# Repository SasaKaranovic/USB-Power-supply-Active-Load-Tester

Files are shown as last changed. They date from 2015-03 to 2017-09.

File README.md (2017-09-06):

# USB Power supply Active Load Tester

The USB Power Supply Active Load Tester is a unit designed for testing
the quality of power supplies.  The idea was to create a low-cost,
precise device for simultaneous measurement of voltage and current
draw from a device under test. This is one of my weekend projects that
I have decided to release to the public. If you are interested in my
other projects you can see them on [my homepage].

### Device Features:
- Open Source and Open Hardware
- Modular design, easy to understand and change/adapt to your needs
- Uses widely available and off-the shelf components
- Bill of Material is below $10
- Integrated USB-to-Serial converter for easier interface with the device
- API for communicating with PC
- Recording Voltage vs Amps data and graphing the results
- Easy to use

### Example plot of Voltage vs Current for 5V 1A adapter
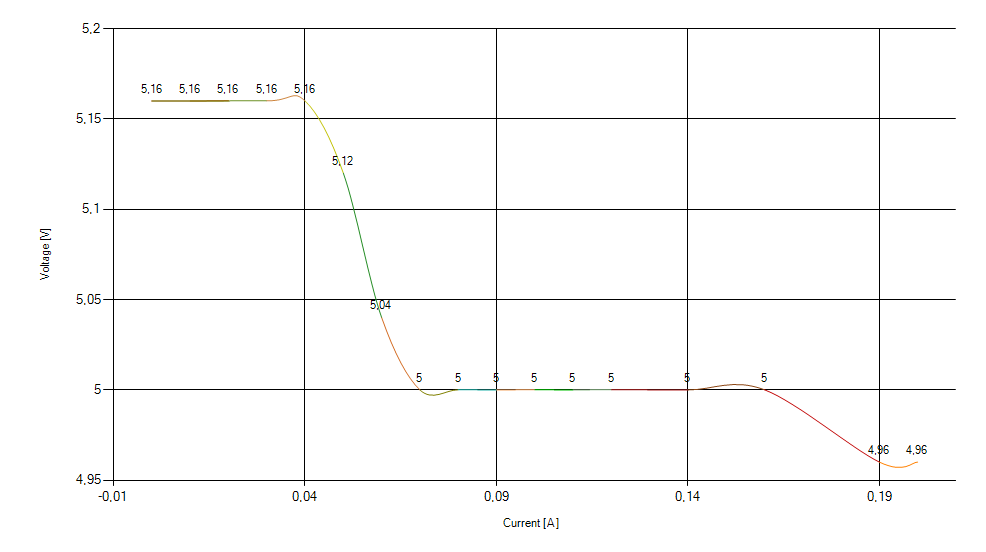
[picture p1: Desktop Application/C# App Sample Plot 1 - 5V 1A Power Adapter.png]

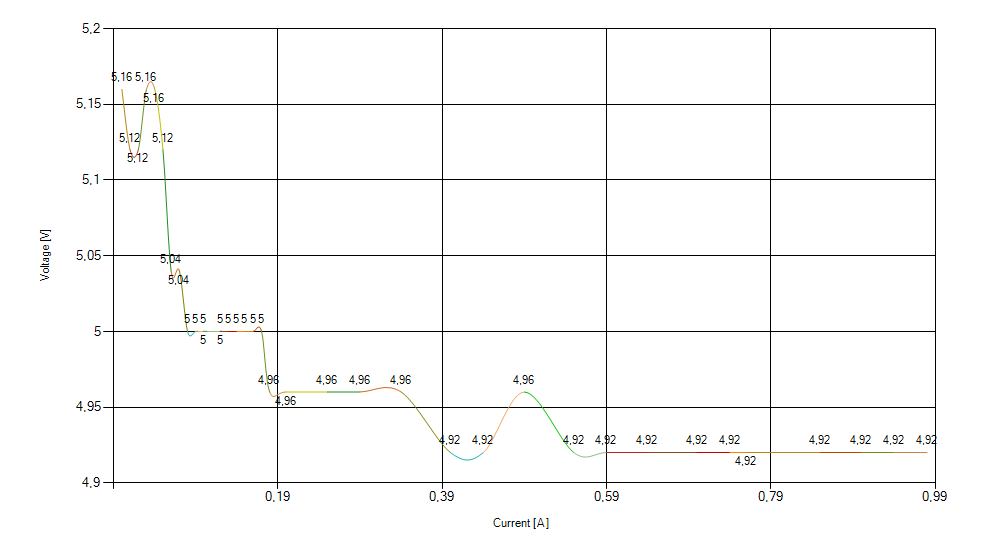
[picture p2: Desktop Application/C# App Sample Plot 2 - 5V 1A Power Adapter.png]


### Basic capabilities:
- PSU under test max voltage 55V
- Current Load of 5A (or more by lowering current sense resistor value)
- Current and Voltage measurement accuracy is below 5%

### Component list and estimated price:
- 1x - PIC16F1829 [$1.6]
- 1x - MCP6002 Rail-to-Rail OpAmp [$0.69]
- 1x - MCP4726 12bit DAC [$0.96]
- 1x - IRF L3705 Logic Level N-MOSFET [$0.5]
- 1x - CH340T USB-to-Serial converter [$0.99]
- 10x - Current sense 1 ohm 1% 1/2W resistor
- miscellaneous (resistors and capacitors)

Total components cost should be way under $10.

### How to build your own PAL Tester:
 If you are going to use photo etching or toner transfer method to make DIY board, there are bottom layer printouts in the Hardware folder that are ready for you to print and create a board via your favourite PCB manufacturing technique.

Once you have finished with developing, cleaning and drilling the board, in Hardware folder you have a file "Component-placement.png" which shows how and where to position components.

If you want to make changes or review the design, Schematic files (in .pdf) and Altium project files are available for download in Hardware folder. Open the design files in Altium or convert them to your favourite CAD and edit them.

### Device operation for laymans:
The microcontroller sets the voltage on the positive input of the Op
amp through a Digital-to-Analog converter (DAC).

The output of the op-amp then drives the N-MOSFET that allows current to flow.  

The negative input of op-amp is connected to the sensing resistor (Rs) that is between the source of the N-MOSFET and GND.

The voltage across Rs (and thus voltage on the negative input of the op-amp) is proportional to the current flowing through the resistor. For 1 Ohm resistor, V=1 ohm x Current draw.

Since an op-amp "tries to equalize positive and negative inputs", suppose the voltage on its positive input is 1V. To equalize positive and negative inputs, the voltage on the negative input (the one that is connected to Rs) must also be 1V, so the op-amp drives the N-MOSFET to open, allowing the current to flow, but only enough to make 1V on the negative input. Calculating the current draw from the above mentioned formula, we see that in this example, the current draw will be 1A.

### Development

Want to contribute? Great!

Currently there is a C# .NET application written for interfacing with the device. It works but it's very rough and very basic. If you are interested in writing an application in Python, C++, C or any other language, please do. I would greatly appreciate that. Also if you need help or more information, feel free to contact me over Skype, Email, IRC or whatever way you like. :)

Also if you think you can help in any other way, please do. Any kind of help is greatly appreciated.

Special thanks to
----
- Loshki from #electronics @ Freenode
- Your name here :)

Contact me
----
[Sasa Karanovic Home] - Follow me [@Twitter] - [Facebook] - [YouTube] - [EMail]

License and Disclaimer
----
You are using this software and hardware at your own risk.

**Open Source, Open Hardware. Do WHATEVER your want :)**

[Sasa Karanovic Home]:http://sasakaranovic.com
[my homepage]:http://sasakaranovic.com
[YouTube]:http://sasakaranovic.com/youtube
[@Twitter]:http://twitter.com/iSaleK
[Facebook]:https://www.facebook.com/SasaKaranovic
[EMail]:mailto:sale@mrdnise.com

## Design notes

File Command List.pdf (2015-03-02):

## PAL Unit (Power supply Active Load)

# Command list

Command | Value range | Description | Example
S:xxxx | 0 – VCC* | Set DAC output voltage to xxxx mV. For 1Ω sens resistor current draw will be equal to DAC output voltage. | S:0500 → Sets target current draw to 0.5A [for 1Ω sens resistor]
C:M00x | 0 or 1 | Continous reading off/on. In continuous mode device sends Current and Voltage readings every delay* period of time. | C:M001 → ON C:M000 → OFF
C:Dxxx | 1 to 255 | Continuous mode delay period. Device will wait for xxx * 100ms before sending new values. | C:D005 → Device will send readings every 5 * 100ms = 500ms
C:Onnn | / | Issue on demand read. Device will read Power Supply under test voltage, current draw and DAC output voltage and send them over UART. | C:0xxx → Read current values and send over UART once.

# Example output

Command | What happens | Example output on UART
S:0500 | DAC output voltage will be set to 500mV or 0.5V If 1Ω sens resistor is used, device will try to draw 500mA or 0.5A from the Power Supply Under Test. | PSV:12.00V\r\n PSI:0.50A\r\n
C:M001 | Continuous mode is turned on. Device will send readings every *delay* seconds. | PSV:12.00V\r\n PSI:0.50A\r\n
C:Onnn | Issue a on-demand read request. Device will read values and send them over UART but only once. | PSV:12.00V\r\n PSI:0.50A\r\n OPA:0.50V\r\n

http://sasakaranovic.com/project/USB-PAL-Tester/https://github.com/coldkeyboard/USB-PAL-Tester

Version 0.6
2015-02-23

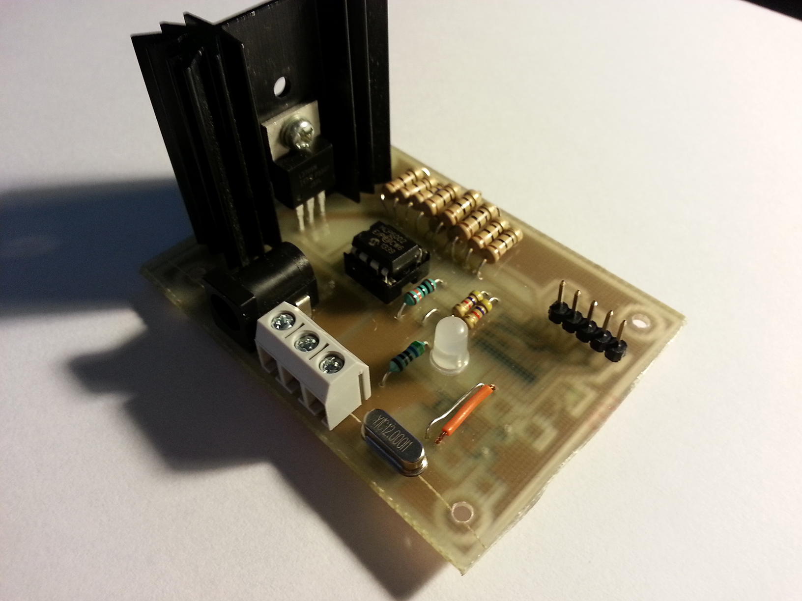
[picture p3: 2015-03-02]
Hardware/PAL Unit Top.jpg

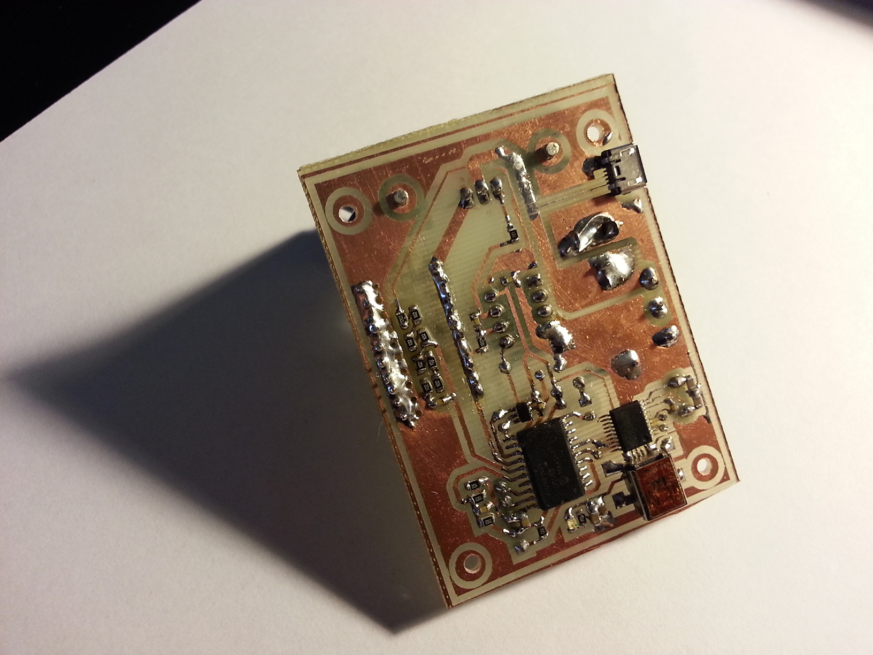
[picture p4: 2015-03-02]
Hardware/PAL Unit Bottom.jpg

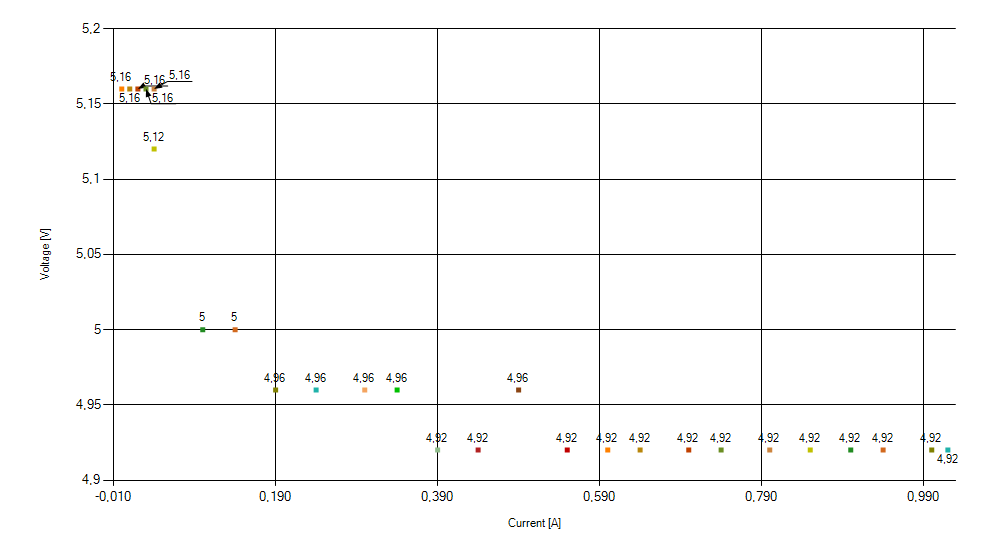
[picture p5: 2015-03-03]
Desktop Application/C# App Sample Point Plot 3 - 5V 1A Power Adapter.png

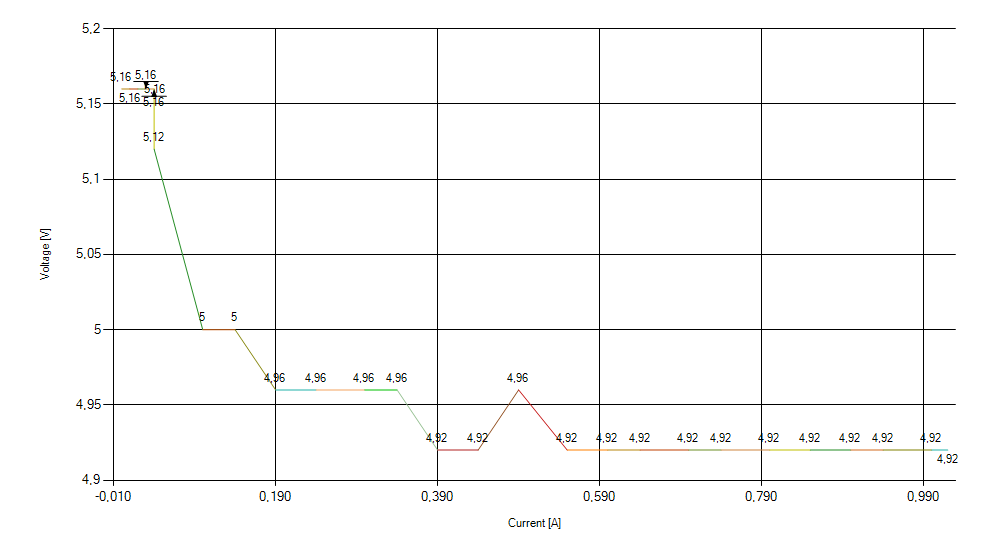
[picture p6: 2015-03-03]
Desktop Application/C# App Sample Line Plot 3 - 5V 1A Power Adapter.png

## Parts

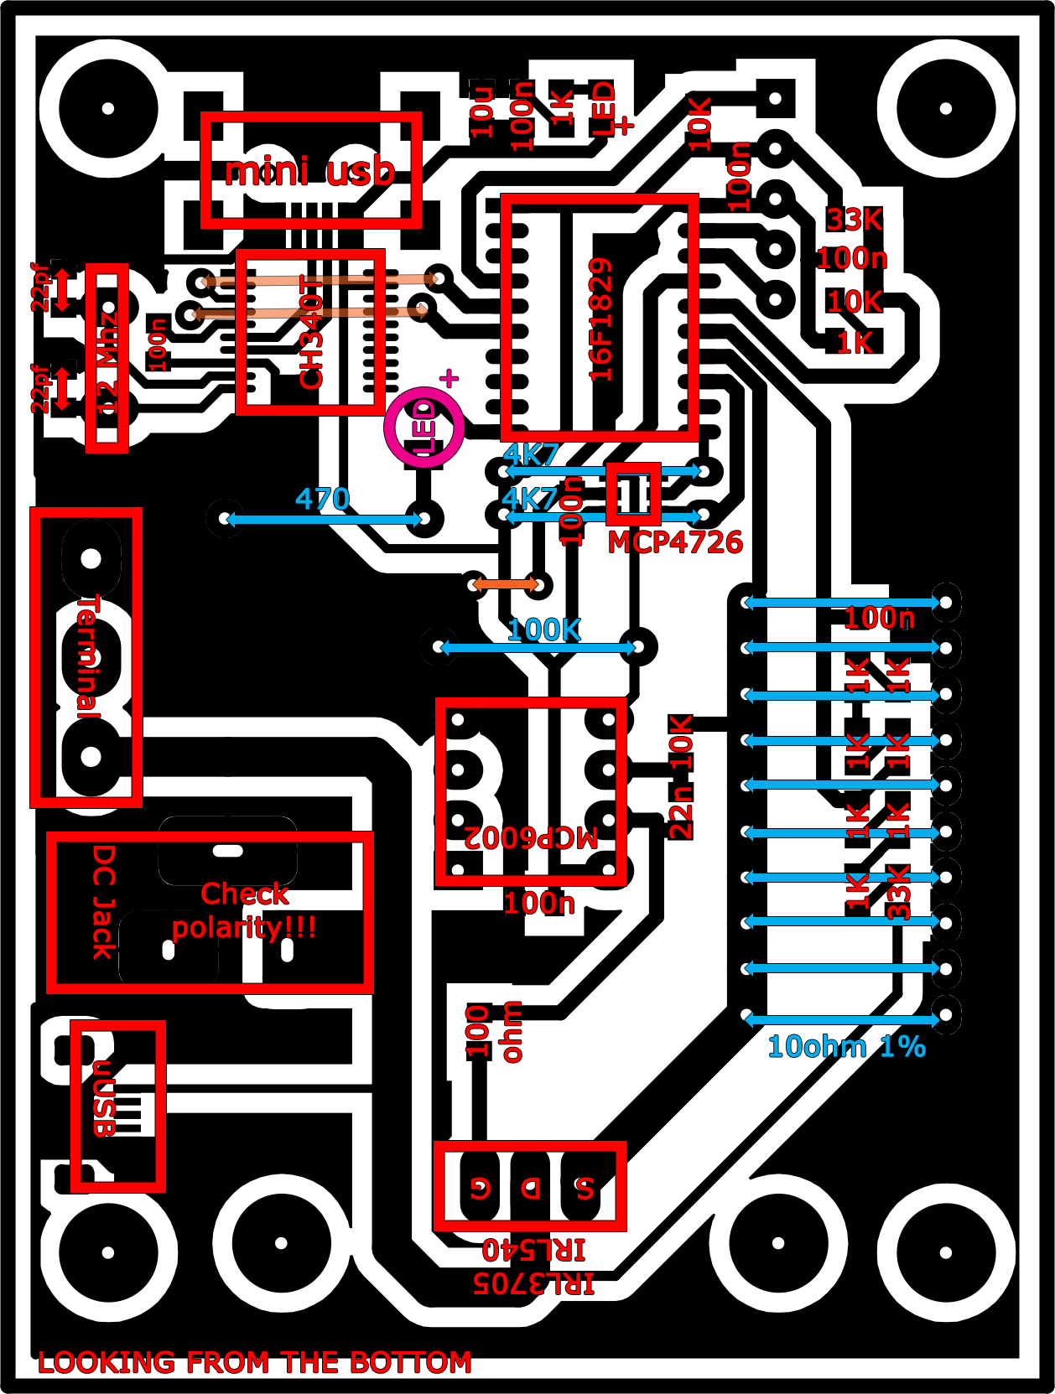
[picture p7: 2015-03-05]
Hardware/Component-placement.png

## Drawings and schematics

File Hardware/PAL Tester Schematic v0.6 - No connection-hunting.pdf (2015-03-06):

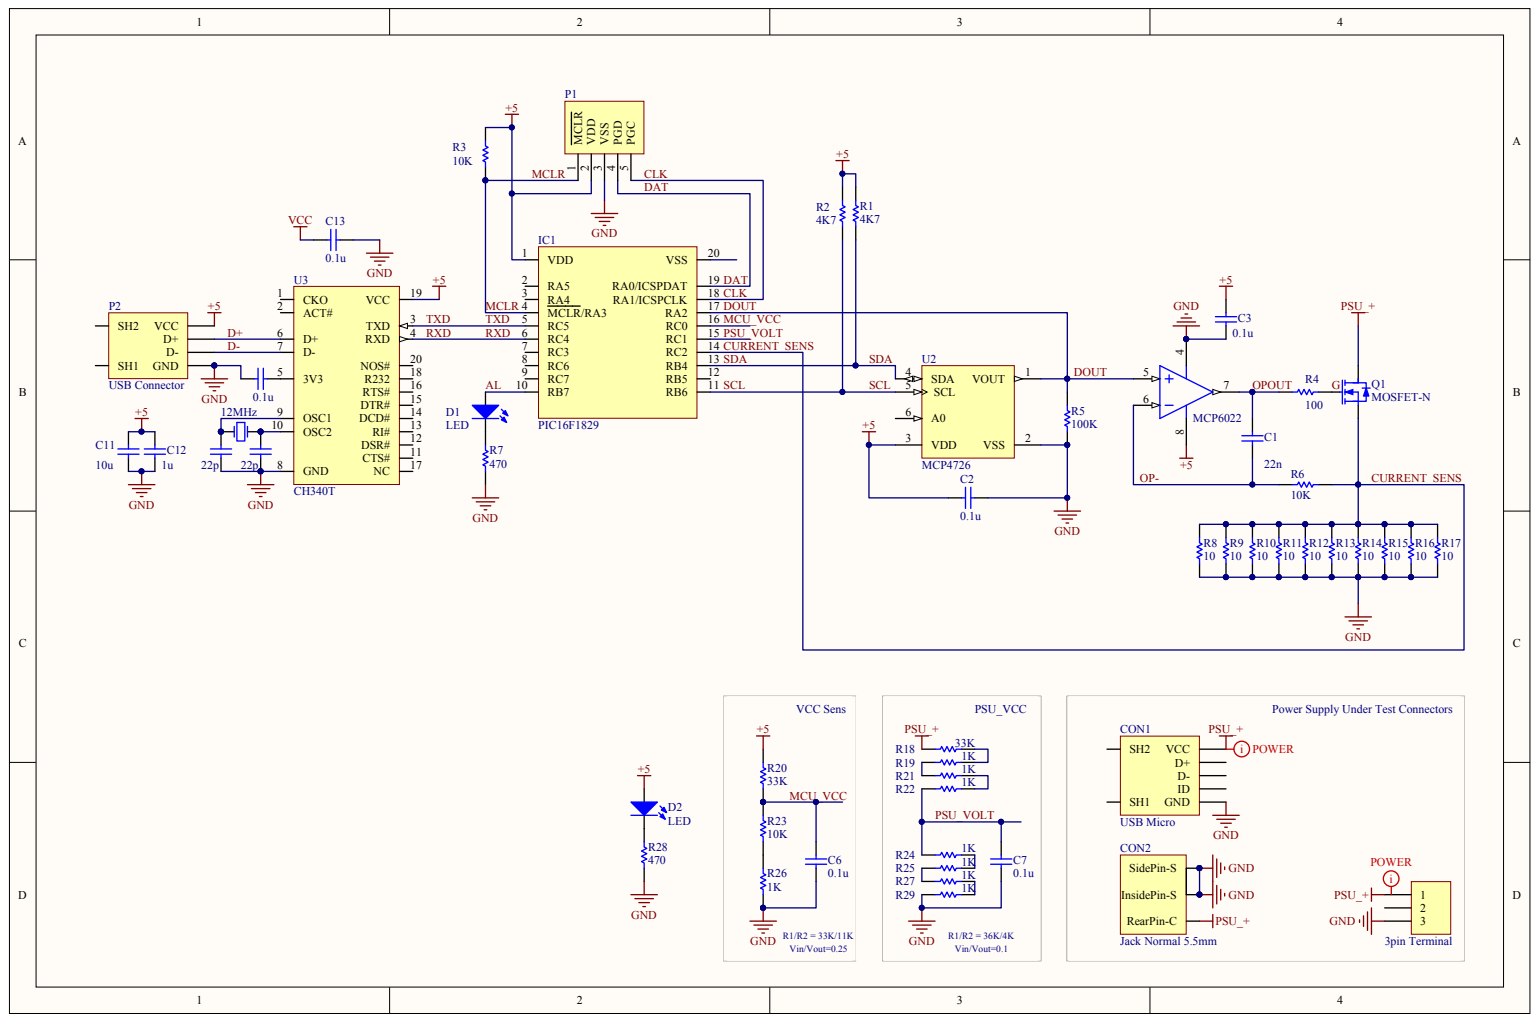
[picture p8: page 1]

Power Supply Under Test Connectors

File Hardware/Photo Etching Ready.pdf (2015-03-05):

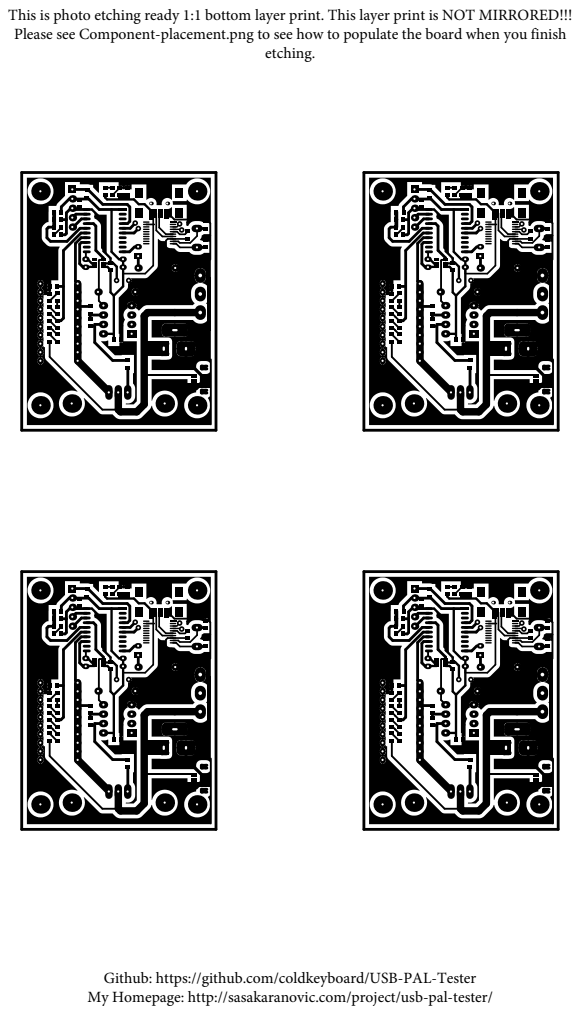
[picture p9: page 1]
etching.

This is photo etching ready 1:1 bottom layer print. This layer print is NOT MIRRORED!!!
Please see Component-placement.png to see how to populate the board when you finish

Github: https://github.com/coldkeyboard/USB-PAL-Tester
My Homepage: http://sasakaranovic.com/project/usb-pal-tester/

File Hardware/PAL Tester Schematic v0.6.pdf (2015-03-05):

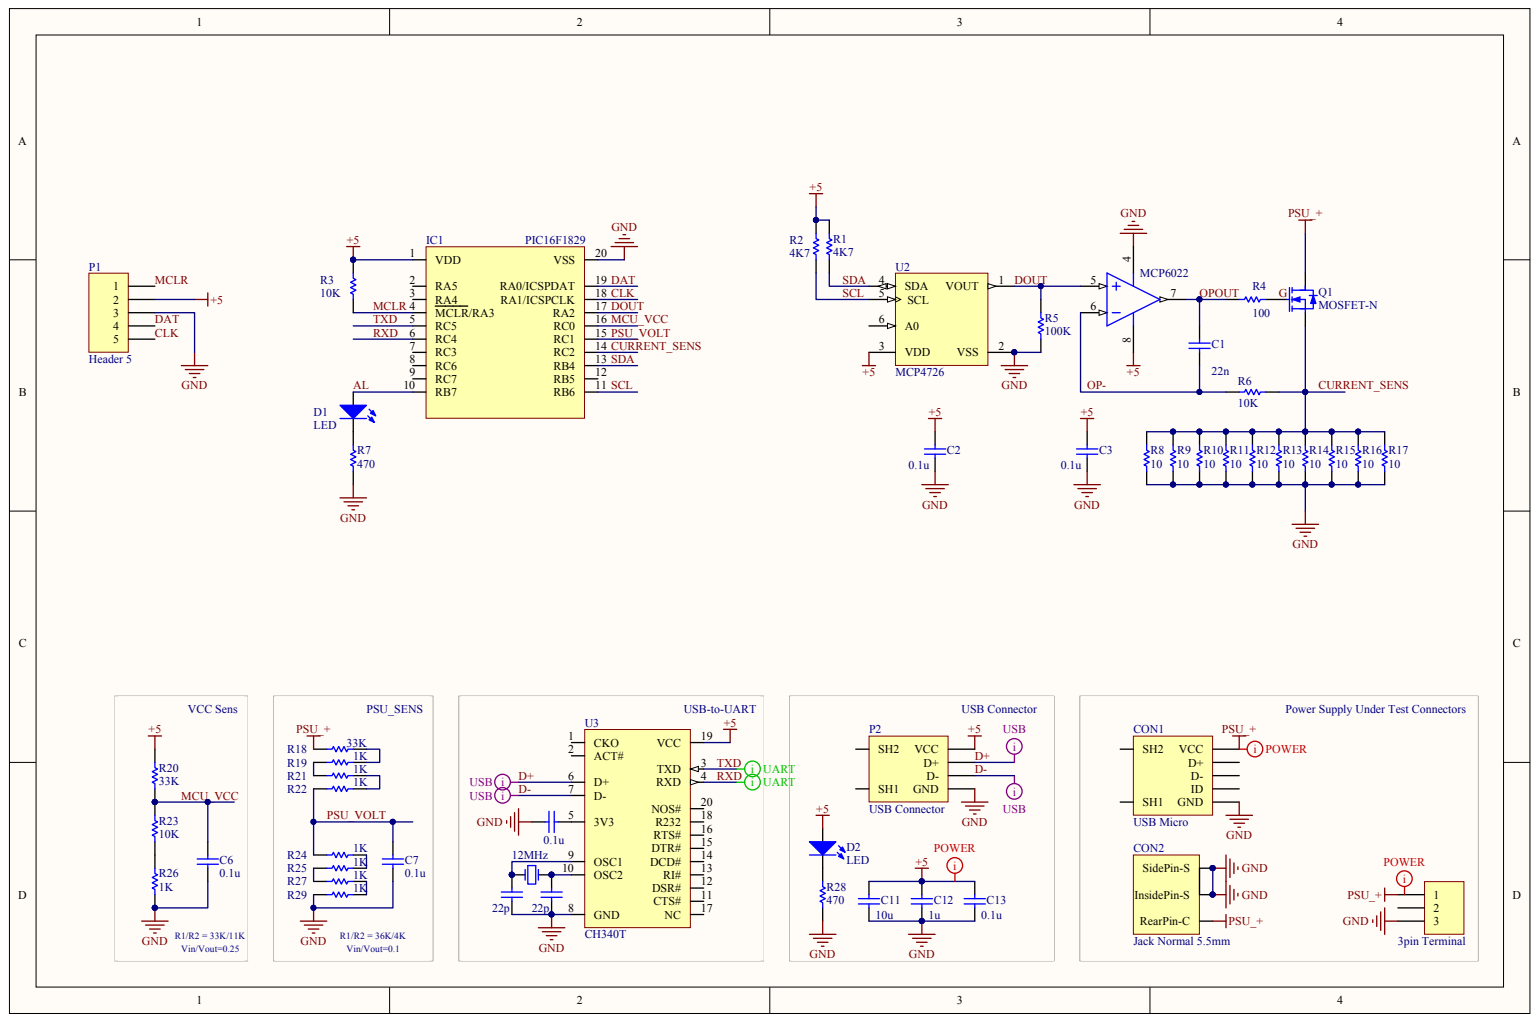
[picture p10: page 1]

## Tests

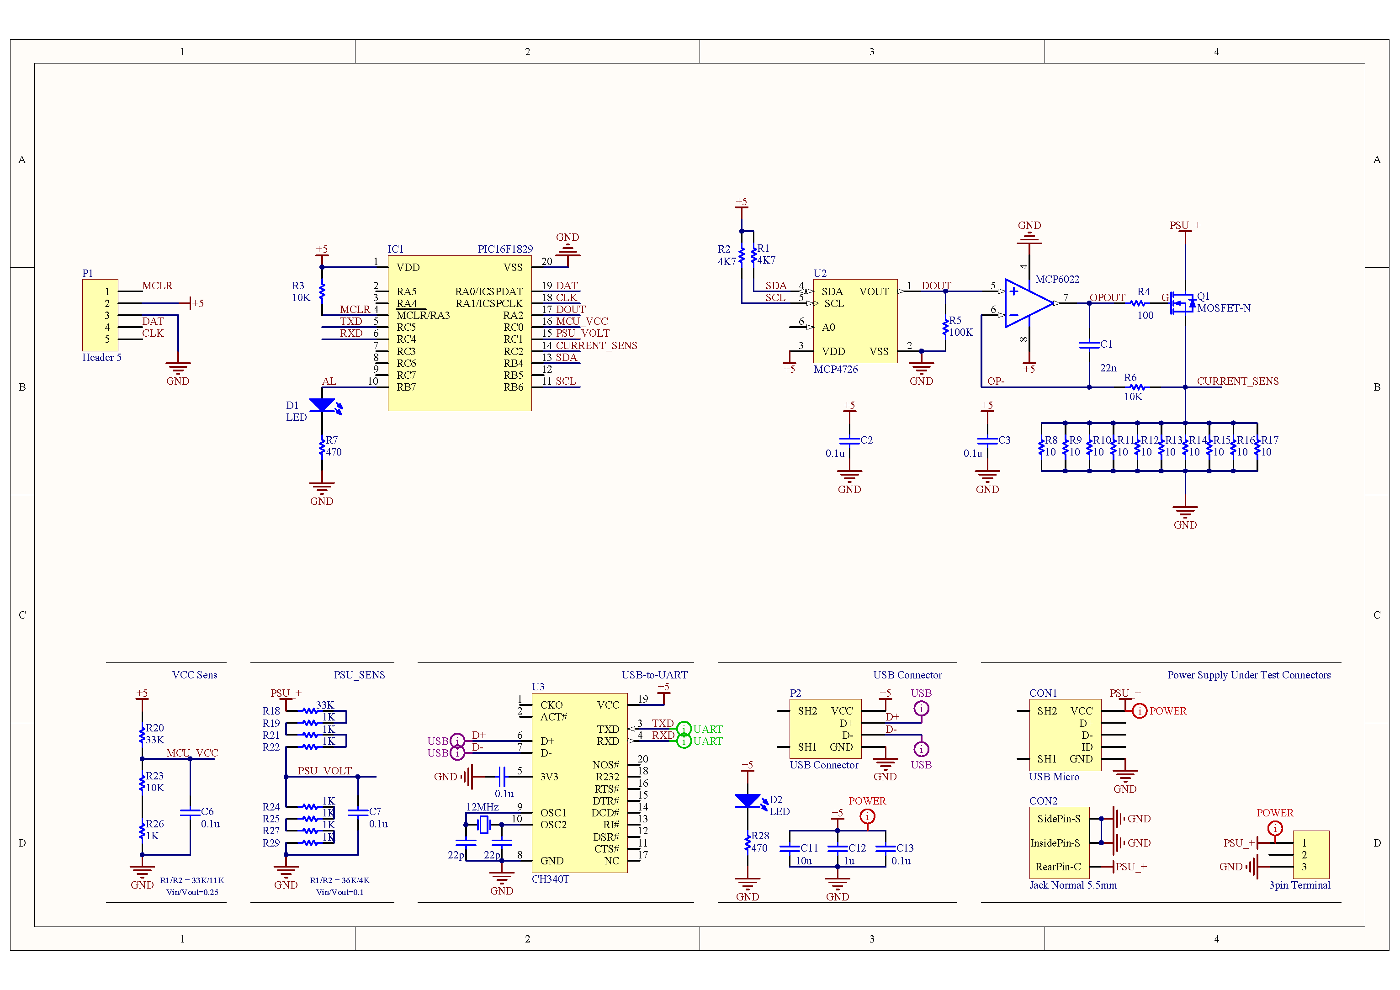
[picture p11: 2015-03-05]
Hardware/PAL Tester Schematic v0.6.png

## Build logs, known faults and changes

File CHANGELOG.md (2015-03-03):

# Change Log
All notable changes to this project will be documented in this file.
This project adheres to [Semantic Versioning](http://semver.org/).

## [0.6.1] - 2015-03-03
### Added
- Added examples of Line, SpLine and Point charts to /Desktop Application/ folder.

### Changed
- Desktop Application now has options to clear graph, change graph type and save graph (was available from the beginning but was hidden under chart double-click and by default saved at c:\).
- Desktop Application should now display proper values for X-axis

## [0.6] - 2015-03-01
### Added
- C# Source files and compiled application written in C# to interface with the device
- Command List.pdf - Contains commands list, explanations and example input and UART output.
- Command [C:M00x] to chose between continuous sending of Voltage and Current draw readings
 and on demand. x means 1=Continuous, 0=On Demand
- Command [C:Dxxx] to set delay in continuous mode. xxx is delay of xxx*100ms. [eg. 005 -> 500ms delay]
- Reading of device VCC rail via resistor divider and using that data to further
self-calibrate the device.
- Using VCC_voltage/4096 as DAC quant instead of 5V/4096 making the device more precise
and immune to the VCC rail noise/fluctuation.
- Added function to issue self recalibrate command.
- ACTIVITY LED to notify user when changes have been received/applied and as a general
indication of activity.
- MCU POWER LED for indication if device is powered up
- PSU under test VOLTAGE PRESENT LED indicating that MCU is measuring voltage above 1V
between + and - leads of the PSU under test.

### Changed
- \r\n moved from the start of the string to the end of the string.
- UART Receiver Interrupt handling routine (aka RX ISR) has become too big so I've moved it
to separate file called ISRFunctions.h and ISRFunctions.c This should improve code readability
and also simplify the process of adding support for new commands.
ISR is still big but at this moment it "has to be". At least it should be easy to follow.
- UART Set/Read API made more coherent. Using S:xxxx for SET voltage and C:xxxx for configuring
and communicating with the device.
- Command and function names have been renamed to further reflect what peripheral/device
they belong to and set to easier to read format. (still a lot of work to do here...)

## [0.5] - 2015-02-01
### Added
- General "human readable" API to set/read data from the device. Hopefully making
use of this device with other software easier and more pleasant. :)

### Fixed
- Issues where after disconnecting UART or re-powering the device, last programmed
target current draw will remain and be immediately set as new target causing unwanted
stress or overload on the PSU under test
- Overflowing the DAC/VCC value will result in no status change instead of resetting to 0A draw.
Also an error message will be sent over UART notifying the user.

## [0.4] - 2015-01-21
### Added
- Code to support DAC I2C communication.
- Code to support UART setting target current draw from the PSU under test.

### Changed
- Modified schematic to house potentiometer with MCP4726 (12bit DAC) to enable users to set
target current draw via UART or set manual mode.

## [0.3] - 2015-01-18
### Changed
- Switched to using 5V rail for MCU.
- Switched to using MCP4002 (rail-to-rail) OP-Amp instead of LM324.
- Miscellaneous (minor) changes to voltage dividers and sensing resistor.

## [0.2] - 2015-01-17
### Changed
- Changed function descriptions and names to be more coherent.

### Added
- Reading voltage from potentiometer (besides PSU VCC and voltage on sensing resistor).
- Functions to send VCC, Resistor Voltage and PSU Voltage over UART in more convenient form.

## [0.1] - 2015-01-15
### Added
- Initial build.

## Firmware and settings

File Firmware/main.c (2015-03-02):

/*
 *  Project     : Programmable Active Dummy Load
 *  Code Version: 0.6 (see change log for more information and what's changed)
 *  Compile with: Microchip XC8 v1.31 or up (free compiler)
 *  Hardware    : - PIC16F1829
 *                - MCP4726   (12bit DAC)
 *                - MCP6002   (2x Rail-to-Rail OP-Amp)
 *                - Logic Level N-MOSFET (IRLxx in TO-220 case)
 *                - USB-to-UART converter (FTDI, CH340 or any other)
 *
 *  Description : As the title implies, this is the source code of the programmable active load
 *  unit. Latest source code, design files, schematic, Bill of Material, HOW-TO and lot's of other
 *  useful information about this project can be found on:
 *  My Homepage: http://sasakaranovic.com/projects/usb-pal-tester/
 *  GitHub     : https://github.com/coldkeyboard/USB-PAL-Tester
 *
 * 
 *  Nice feature is that this unit is completely programmable via USB, so you can write little
 *  Python, C, C++, .NET app that will do series of tests on your Power Supply that you want to
 *  check and log that data or plot it on the graphs to see the Power Supply characteristics.
 *
 *  Device configuration and readings are done over the serial communication or UART.
 *  With commands like S:3000 the MCU will set-up DAC to set 3000mV or 3.000V on its output.
 *  DAC Output is connected to + Op Amp which is driving the N-MOSFET that acts like dummy load.
 *  Drain of mosfet is connected to Power Supply + that we want to test/stress. Source of the
 *  MOSFET is connected to the ground via small sensing resistor, 1ohm/1% or better. So having
 *  that in mind, and how OP-amps and MOSFETS work, our dummy load will try to draw 3Amps from
 *  the power supply under test. This little unit will send values like how much Amps are we
 *  drawing from the Power Supply under test, what voltage is across Power Supply under test,
 *  what is the output of the DAC (set current) and etc.
 *
 *  All of the files provided (including but not limited to schematics, source-code, drawings and etc.)
 *  are provided "as-is" without any guarantee and you are using them on your own risk.
 *
 *  All of the files provided are completely open-source. You can do whatever you want with them.
 *
 * I would really appreciate if you would share your designs, modifications, opinions, suggestions
 *  and etc. with me/others so we can all share and collaborate on this project.
 *
 * Also if you like this project or want to show your support, please consider donating (your time,
 *  opinion, review, code modifications, suggestions, request, beer, coffee or anything else you want). :)
 *
 */

#include "main.h"

//Value to send to DAC (VCC/DAC_RESOLUTION * SET_VOLTAGE)
uint16_t DAC_Target_Voltage = 0;

uint16_t ADC_val_VCC            = 0;
uint16_t ADC_val_PSUVCC         = 0;
uint16_t ADC_val_Current        = 0;

//UART ISR values
uint8_t ISR_RX_TEMP;        //Read to this temp variable
uint8_t ISR_RX_BUFF[10];    //Buffer to store RX characters
uint8_t ISR_RX_COUNT = 0;   //Counter for UART RX characters
uint8_t ISR_RX_STATE = 0;   //State of the current UART recieve process
uint8_t ISR_RX_MODE  = 0;   //Are we receiving command to set DAC (S:) or other parameters (C:)

//Configuration
uint8_t CONF_CONTINUOS_SEND         = 0;    //1 -> Send VCC, Current and Voltage Values continuously
uint8_t CONF_CONTINUOS_DELAY        = 10;    //Delay in (this_value)*100ms
uint8_t CONF_CONTINUOS_DELAY_TMP    = 10;    //Temp value used for creating dynamic delay
uint8_t ONDEMAND_PENDING            = 0;

void main()
{
    Device_SetUp();
    Device_Initialize();

    //Measure VCC to make sure our FVR can work properly
    ADC_val_VCC = ADC_MeasureVCC();

    UART_SendVCC(ADC_val_VCC);
    UART_Send_PSU_VoltAmp();
    UART_Send_OPAMP_Voltage();


    while(1)
    {
        if(CONF_CONTINUOS_SEND == 1)      //Continous mode enabled
        {
            UART_Send_PSU_VoltAmp();     //Send PSU Voltage and Current(amps) draw

            CONF_CONTINUOS_DELAY_TMP = CONF_CONTINUOS_DELAY;
            while(--CONF_CONTINUOS_DELAY_TMP) { _delay_ms(100); }
        }
        else if(ONDEMAND_PENDING == 1)
        {
            UART_Send_PSU_VoltAmp();     //Send PSU Voltage and Current(amps) draw
            UART_Send_OPAMP_Voltage();
            ONDEMAND_PENDING = 0 ;
        }

    }
}


//Interrupt Handling
void interrupt ISRRoutine(void)
{
    //USART RX Interrupt
    if (PIE1bits.RCIE && PIR1bits.RCIF) {
        PIE1bits.RCIE  = 0;    //Disable receive interrupts
        PIR1bits.RCIF  = 0;

        ISR_RX_TEMP = RCREG;

        #ifdef _DEBUG_UART_
        //putch(RCREG);   //Loopback sent character
        #endif

        LEDACTIVITY     = 1;
        

        //Check if we are receiving SET command for DAC
        if(ISR_RX_STATE == 0)
        {
            if(ISR_RX_TEMP == 'S')          { ISR_RX_MODE = 1; ISR_RX_STATE    = 1; }
            else if (ISR_RX_TEMP == 'C')    { ISR_RX_MODE = 2; ISR_RX_STATE    = 1; }
            ISR_RX_COUNT    = 0;
        }
        //2nd character must be : to indicate we are receiving S: or C: command
        else if (ISR_RX_STATE == 1 && ISR_RX_TEMP == ':') { ISR_RX_STATE = 2; }
        //followed by 4 ASCII characters
        else if (ISR_RX_STATE == 2 && ISR_RX_COUNT < 4)
        {
     
            ISR_RX_BUFF[ISR_RX_COUNT] = ISR_RX_TEMP;
            ++ISR_RX_COUNT;
            if(ISR_RX_COUNT == 4) { ISR_RX_STATE = 3; }
        }

        if (ISR_RX_STATE == 3)
        {    //Receiving complete. All 4 characters are in ISR_RX_BUFF
            
            if(ISR_RX_MODE == 1) { ISR_SetDAC(ISR_RX_BUFF); }   //Set DAC command received
            else if ( ISR_RX_MODE == 2) { ISR_Command_Mode(ISR_RX_BUFF); }    //Control command is received

            ISR_RX_STATE    = 0;
            ISR_RX_MODE     = 0;
        }

        LEDACTIVITY = 0;

        PIE1bits.RCIE  = 1;    //Enable receive interrupts
        return;
    }
}

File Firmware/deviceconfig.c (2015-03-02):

#include "main.h"

void Device_SetUp()
{
#ifdef _PIC16F1829_H_
    //Configure oscillator for 32MHz (8MHz 4xPLL)
    OSCCONbits.SPLLEN   = 1;        //1 = 4xPLL Is enabled
    OSCCONbits.IRCF     = 0b1110;   //1110 = 8 MHz or 32 MHz HF(see Section 5.2.2.1 ?HFINTOSC?)
    OSCCONbits.SCS      = 0b00;     //00 = Clock determined by FOSC<2:0> in Configuration Word 1.

    //wait for oscillator to stabilise
    while(!OSCSTATbits.HFIOFR);         //1 = HFINTOSC is ready
    while(!OSCSTATbits.HFIOFS);         //1 = HFINTOSC is at least 0.5% accurate
    while(!OSCSTATbits.PLLR);           //1 = 4xPLL is ready



    //Configure Activity LED
    TRISACTIVITY  = OUTPUT;
    LEDACTIVITY   = 0;

#else
#warning "DeviceSetup() function is empty for this device"
#endif
}

void SetUpInterrupts()
{
#ifdef _PIC16F1829_H_
    INTCONbits.PEIE = 1;
    PIE1bits.RCIE   = 1;
    INTCONbits.GIE  = 1;


#else
#warning "SetUpInterrupts() function is empty for this device"
#endif

}


void UARTSetup(uint16_t baudrate)
{
#ifndef _XTAL_FREQ
    #warning _XTAL_FREQ is not defined!;
#endif
#ifdef _PIC16F1829_H_
    //Select and configure RX/TX pins
    APFCON0bits.RXDTSEL = 1;    //1 = RX/DT function is on RC5
    APFCON0bits.TXCKSEL = 1;    //1 = TX/CK function is on RC4

    
    TRISCbits.TRISC5    = INPUT;
    TRISCbits.TRISC4    = OUTPUT;
    LATCbits.LATC4      = 1;

    //Configure baudrate
    BAUDCONbits.BRG16   = 1;    //1 = 16-bit Baud Rate Generator is used
    uint16_t baud = (( (_XTAL_FREQ / baudrate) / 4 ) - 1);
    SPBRGL  = (baud & 0xFF);
    SPBRGH  = (baud >> 8);

    //Configure TX and RC registers
    TXSTAbits.BRGH  = 1;        //1 = High speed
    TXSTAbits.TXEN  = 1;        //1 = Transmit enabled
    RCSTAbits.CREN  = 1;        //1 = Enable Receive
    RCSTAbits.SPEN  = 1;        //1 = Serial port enabled (configures RX/DT and TX/CK pins as serial port pins)

    _delay_ms(10);  //Give UART some time to stabilise (not necessary)

#else
#warning "SetupUART() function is empty for this device"
#endif
    
}





void putch(uint8_t data) {
    while(TXSTAbits.TRMT != 1);
    TXREG = data;
}



void Device_Initialize()
{
    UARTSetup(57600);
    LEDACTIVITY = 1;
    _delay_ms(100);
    UART_Debug("UART IS ON\r\n");
    ADC_Config();
    UART_Debug("ADC IS ON\r\n");
    I2C1_Setup();
    UART_Debug("I2C is ON\r\n");

    //Initialize DAC to 0V
    mcp4726_SetValue(0);
    _delay_ms(500);
    LEDACTIVITY = 0;

    //SetUp Interrupts
    SetUpInterrupts();

}

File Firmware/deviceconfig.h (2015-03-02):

#ifndef DEVICECONFIG_H
#define	DEVICECONFIG_H

//Configuration bits for PIC16F1829
#ifdef _16F1829
// CONFIG1
#pragma config FOSC = INTOSC    // Oscillator Selection (INTOSC oscillator: I/O function on CLKIN pin)
#pragma config WDTE = OFF       // Watchdog Timer Enable (WDT disabled)
#pragma config PWRTE = OFF      // Power-up Timer Enable (PWRT disabled)
#pragma config MCLRE = ON       // MCLR Pin Function Select (MCLR/VPP pin function is MCLR)
#pragma config CP = OFF         // Flash Program Memory Code Protection (Program memory code protection is disabled)
#pragma config CPD = OFF        // Data Memory Code Protection (Data memory code protection is disabled)
#pragma config BOREN = ON       // Brown-out Reset Enable (Brown-out Reset enabled)
#pragma config CLKOUTEN = OFF   // Clock Out Enable (CLKOUT function is disabled. I/O or oscillator function on the CLKOUT pin)
#pragma config IESO = ON        // Internal/External Switchover (Internal/External Switchover mode is enabled)
#pragma config FCMEN = ON       // Fail-Safe Clock Monitor Enable (Fail-Safe Clock Monitor is enabled)

// CONFIG2
#pragma config WRT = OFF        // Flash Memory Self-Write Protection (Write protection off)
#pragma config PLLEN = OFF       // PLL Enable (4x PLL disable)
#pragma config STVREN = ON      // Stack Overflow/Underflow Reset Enable (Stack Overflow or Underflow will cause a Reset)
#pragma config BORV = LO        // Brown-out Reset Voltage Selection (Brown-out Reset Voltage (Vbor), low trip point selected.)
#pragma config LVP = ON         // Low-Voltage Programming Enable (Low-voltage programming enabled)



//Activity (LED Anode) PIN
#define TRISACTIVITY    TRISBbits.TRISB7
#define ANSELACTIVITY   ANSELBbits.ANSB7
#define LEDACTIVITY     LATBbits.LATB7


/*
 *
 *          ADC PINS
 *
 */

//DAC Output (trough voltage divider) voltage Sensing
//RA2 - PIN17 - AN2
#define TRISDACVOLTAGE     TRISAbits.TRISA2
#define ANSELDACVOLTAGE    ANSELAbits.ANSA2
#define PINDACVOLTAGE      LATAbits.LATA2
#define ADCDACVOLTAGESENSE 0b00010


//Power Supply Under Test Voltage Sensing
//RC1 - PIN15 - AN5
#define TRISVOLTAGE         TRISCbits.TRISC1
#define ANSELVOLTAGE        ANSELCbits.ANSC1
#define PINVOLTAGE          LATCbits.LATC1
#define ADCPSUVOLTAGESENSE  0b00101


//Current Draw Sensing
//RC2 - PIN14 - AN6
#define TRISCURRENT     TRISCbits.TRISC2
#define ANSELCURRENT    ANSELCbits.ANSC2
#define PINCURRENT      LATCbits.LATC2
#define ADCCURRENTSENSE 0b00110


//MCU VCC rail voltage (trough voltage divider) Sensing
//RC0 - PIN16 - AN4
#define TRISVCC         TRISCbits.TRISC0
#define ANSELVCC        ANSELCbits.ANSC0
#define PINVCC          LATCbits.LATC0
#define ADCVCCSENSE     0b00100



#define EnableInterrupts()  (INTCONbits.GIE = 1)
#define DisableInterrupts() (INTCONbits.GIE = 0)




#endif

void Device_SetUp();
void Device_Initialize();
void Device_SetUpInterrupts();
void UART_Setup(uint16_t baudrate);
void putch(uint8_t data);


#endif	/* DEVICECONFIG_H */
